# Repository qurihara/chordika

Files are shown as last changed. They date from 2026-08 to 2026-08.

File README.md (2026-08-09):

# Chordika &amp; Recorika

**Card-sized 3D-printed whistles. Swap a card, change the key.**

日本語版は [README.ja.md](README.ja.md) をご覧ください。

Eight fipple pipes are 3D-printed into a credit-card-sized plate (85.6 × 54 × 4 mm).

- **Chordika** — blow any three adjacent pipes in one breath and a tuned triad sounds.
  Twelve cards cover every key, and the position-to-chord mapping is *identical* on all of
  them, so the same hand motion transposes when you swap the card.
- **Recorika** — the scale counterpart: one octave of a major scale, lowest pipe on the
  left, highest on the right. Available in G, A♭ and A.

The data is published, so anyone with a 3D printer can make the same thing. Each card is exactly credit-card sized, so it travels in a wallet or a card case.

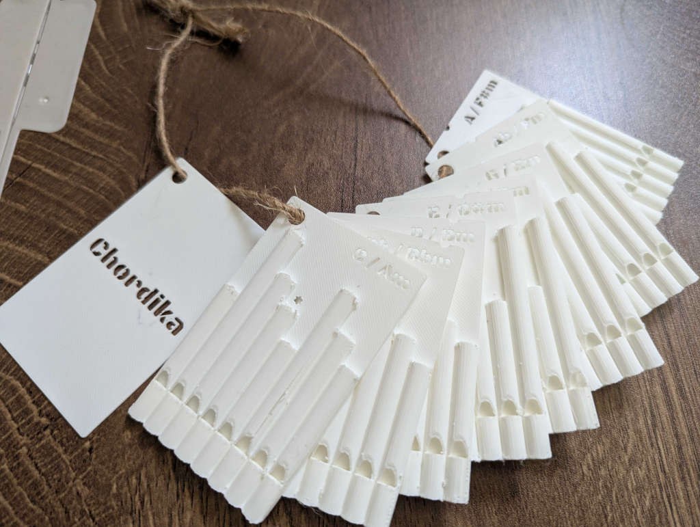
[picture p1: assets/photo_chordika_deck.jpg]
The twelve Chordika cards


**Project site: https://unryu.org/chordika/**

## The layout

On every Chordika card, the same pipes give the same chord function:

| Pipes | 1·2·3 | 2·3·4 | **3·4·5** | 4·5·6 | 5·6·7 | 6·7·8 |
|---|---|---|---|---|---|---|
| Chord | V | iii | **I** | vi | IV | ii |
| on C / Am | G | Em | **C** | Am | F | Dm |
| on G / Em | D | Bm | **G** | Em | C | Am |

Positions are counted from the left, with the windows facing up and the mouthpiece edge
towards you. The tonic pipe is marked with a ＊ on the card.

Each card therefore carries a major key *and* its relative minor. Only vii° (the
diminished triad) is missing.

This works because the notes follow the **degree chain 2·4·6·1·3·5·7·2** rather than pitch
order, which makes every three adjacent pipes a diatonic triad. On the card that chain runs
from the right-hand end towards the left.

## What's in this repository

```
index.html          project site (Japanese / English)
stl/                print data — 12 Chordika cards, 3 Recorika cards, 1 cover, 2 box parts
stl/inverted/       bonus: the 12 Chordika cards with the pipe order mirrored
3mf/                pre-sliced files for the Bambu Lab A1 mini (PLA), the same 18 items
3mf/inverted/       the same 12 inverted cards, pre-sliced
video/              short clips of the cards being played
assets/             cheat sheets (JA/EN), chord maps for all 12 keys, photos and figures
```

**Hear them:** start with the [demo video on YouTube](https://www.youtube.com/watch?v=5BZod5VixxM).
The [project site](https://unryu.org/chordika/) also has short clips — chords on
Chordika, the scale on Recorika, and a tune played on it.

If you own a **Bambu Lab A1 mini**, the files in `3mf/` are already sliced with the
settings below and can be sent straight to the printer. They assume Bambu PLA Basic;
each card is about 8.5 g and takes roughly 1 h 15 min. For any other printer or
filament, slice the STL yourself using the settings below.

## Printing

- **0.08 mm layers, 0.5 mm outer wall.** The pipe walls are thin; do not print coarse.
- **No supports.** Print flat, as-is.
- **One card per plate.** Two cards on one plate double the time per layer, the edges cool
  and shrink, and the card warps. A brim alone will not stop it.
- **Brim about 5 mm, brim-to-object gap 0.** With a gap the brim never fuses to the part
  and holds nothing.
- White PLA works well. Translucent PETG is beautiful — the bores show through the plate.

**Remove any sharp spots before you blow into it.** A fresh print leaves fine burrs and
sharp corners, and this is an instrument you put to your lips — as printed it is not safe.
I have come close to cutting my mouth on one more than once. Run a finger along the card's
edges and around the mouthpieces, and smooth anything that catches with a file or the back
of a knife.

All eight mouthpieces sit in a straight line along one edge of the card: put your lips on
that edge and slide along it. Blow with about as much breath as a recorder — too hard and
the pipe jumps an octave.

## Cover card and box

The **cover** (`chordika_cover.stl`) is a 0.5 mm plate with no pipes and "Chordika" cut
through it. It shares the cards' outline and strap-hole position, so it stacks on top of
the twelve and threads onto the same cord.

The **box** is two parts: an open tray (`chordika_box_base.stl`) and a lid that slips over
its outside (`chordika_box_lid.stl`). All thirteen cards lie flat inside, and the lid
carries the same cut-through lettering as the cover. A scallop on each long side lets you
pinch a card out. Closed, it is about 94 × 62 × 57 mm.

The box holds no pipes, so it prints at **ordinary 0.2 mm layers with no supports** — no
need for the fine settings the cards require.

## How it was designed

Pipe length and pitch were fitted from real printed-and-blown pipes as `f = A/(L+e)`.
Solving it backwards turns a wanted note into a length, so a generator written in Python
(trimesh + manifold3d) emits the whole card from a key name. The plate thickness is fixed
at 0.5 mm — exactly the floor thickness of the pipes; any thicker and it eats into the
bore and the card goes silent.

## Licence

[CC BY-NC-ND 4.0](https://creativecommons.org/licenses/by-nc-nd/4.0/) — see [LICENSE](LICENSE).

**You may** print these for your own use, play them, and share them unchanged with credit,
including non-commercially in classes and workshops.
**You may not** use them commercially (selling prints, paid services) or distribute
modified data. If you want different terms, please get in touch.

---

From the "AI whistle-making" project by Kazutaka Kurihara (Tsuda University).

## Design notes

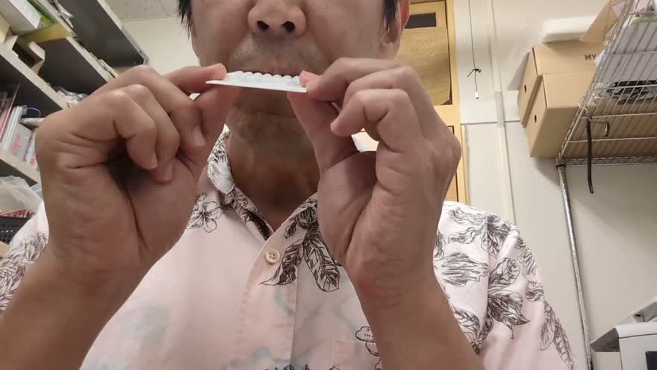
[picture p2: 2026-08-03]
assets/poster_chordika.jpg

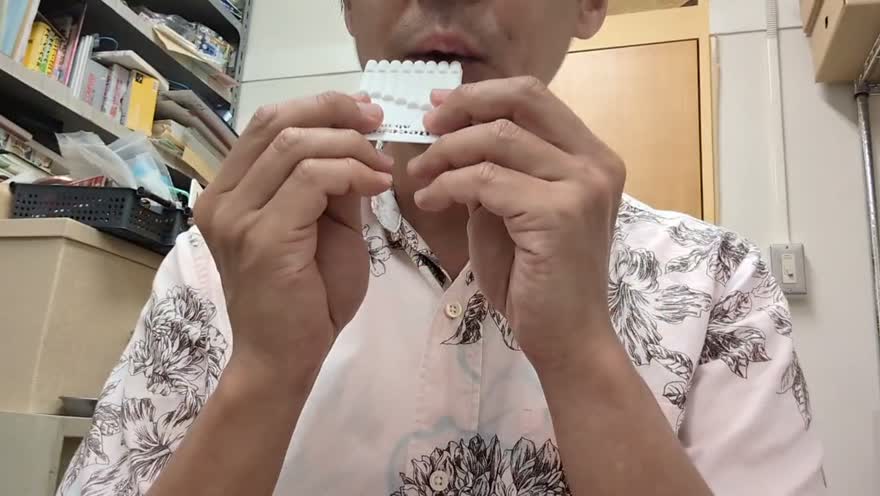
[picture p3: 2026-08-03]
assets/poster_recorika_kirakira.jpg

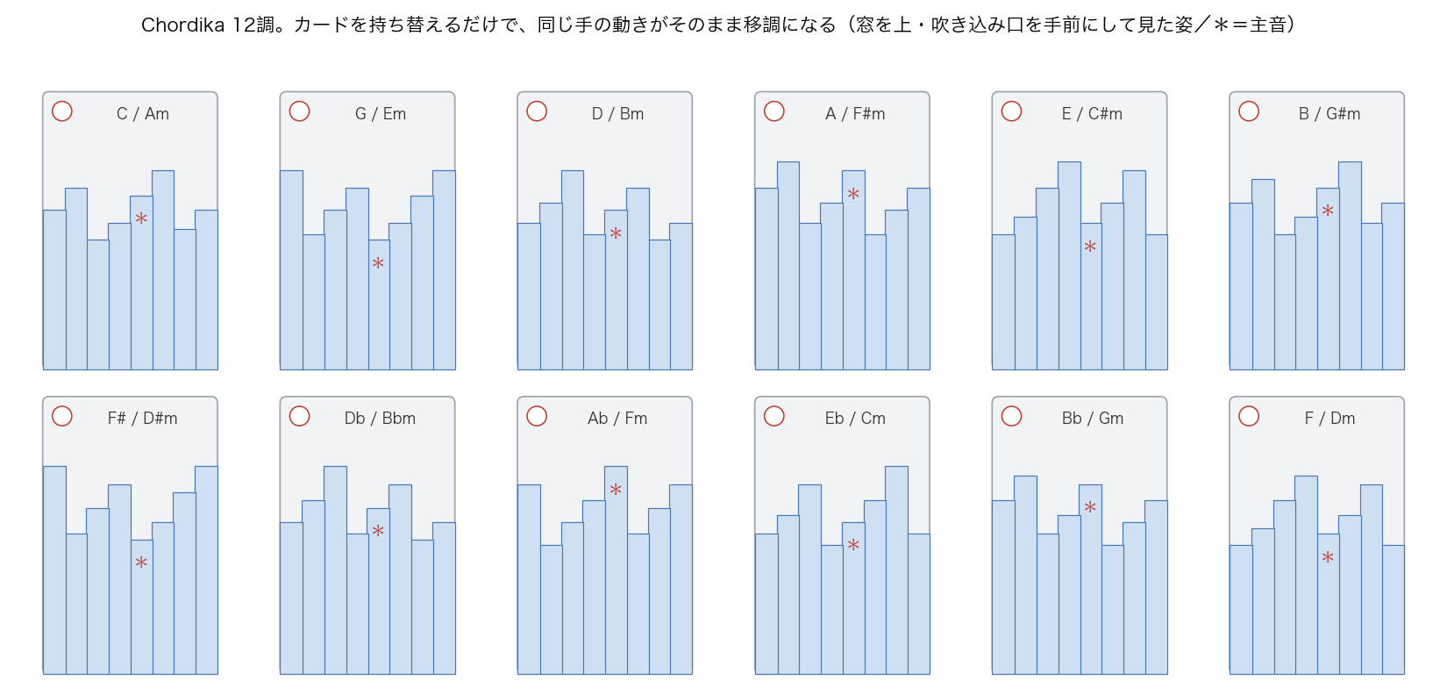
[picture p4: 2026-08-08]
assets/overview_12keys.png

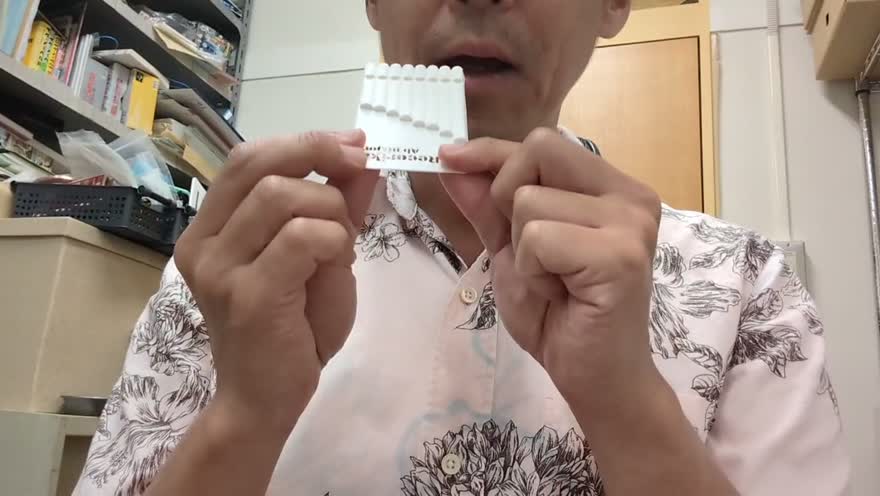
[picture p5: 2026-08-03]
assets/poster_recorika_octave.jpg

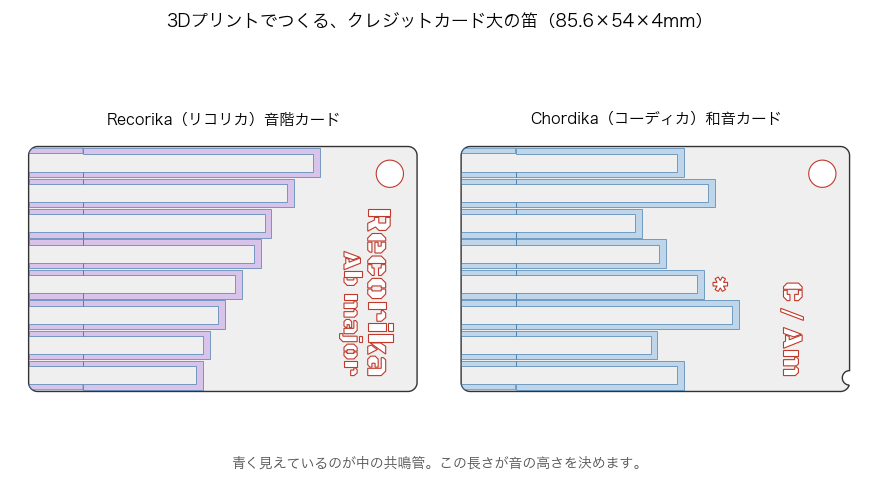
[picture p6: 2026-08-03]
assets/overview_pair.png

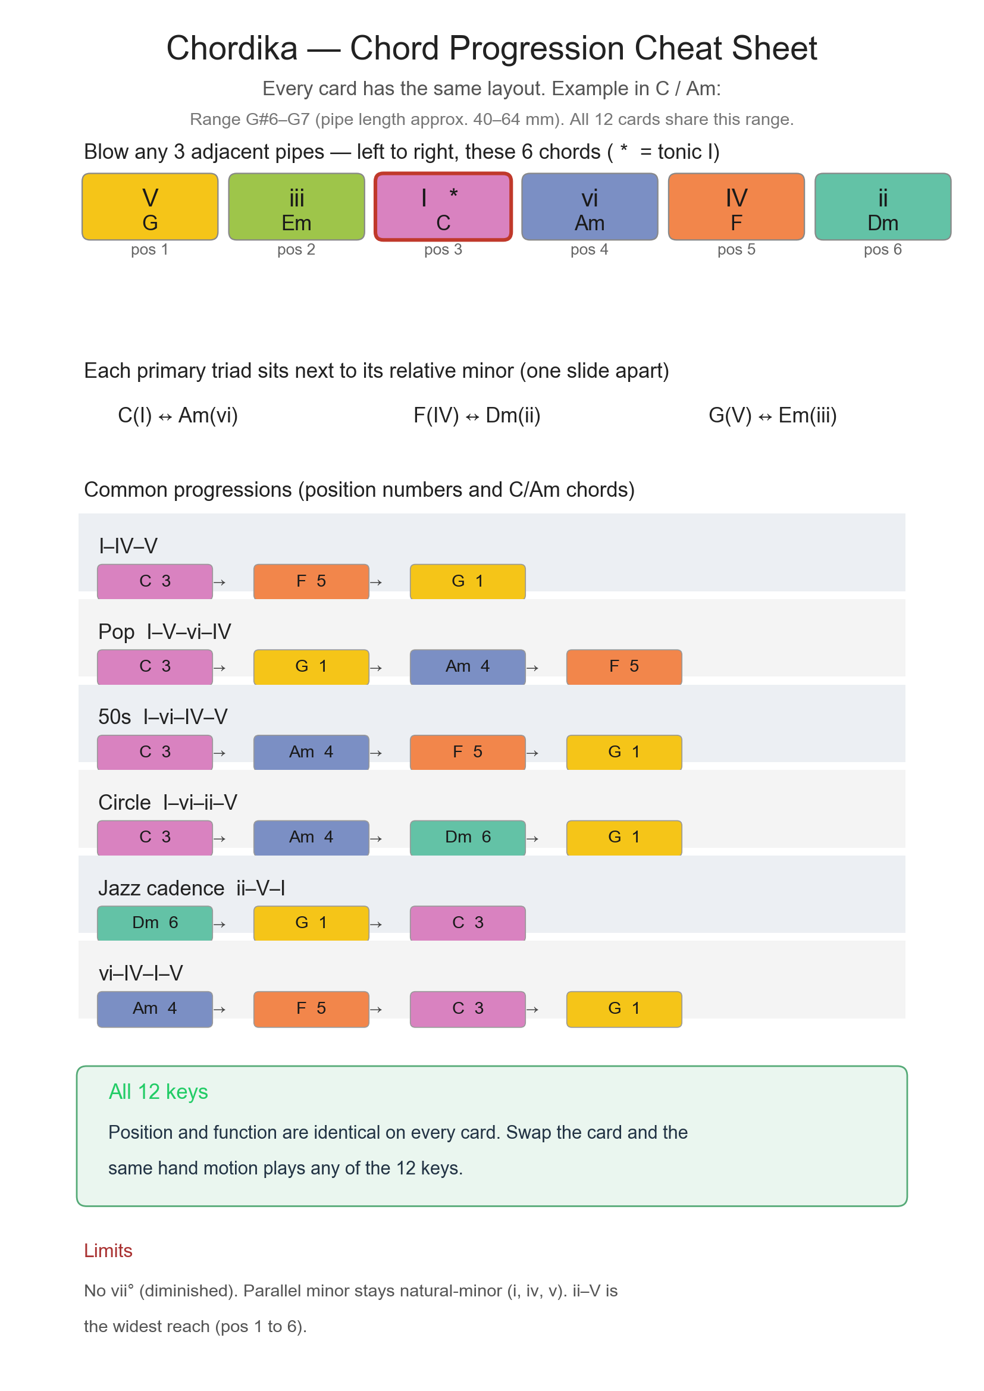
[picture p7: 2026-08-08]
assets/cheatsheet_en.png

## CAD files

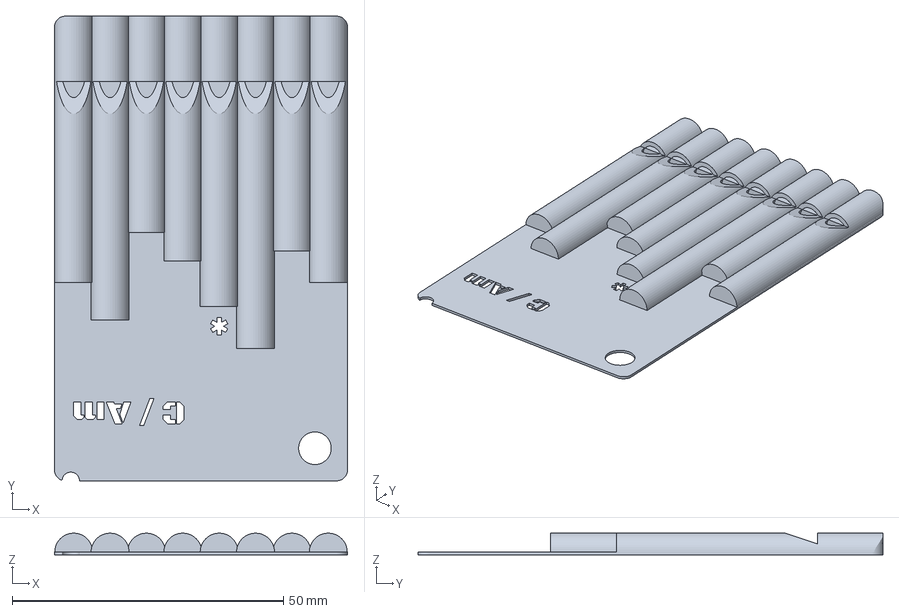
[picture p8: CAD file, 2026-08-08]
3mf/inverted/chordika_C_Am_a1mini_pla.gcode.3mf
54.0 x 85.6 x 4.00 mm

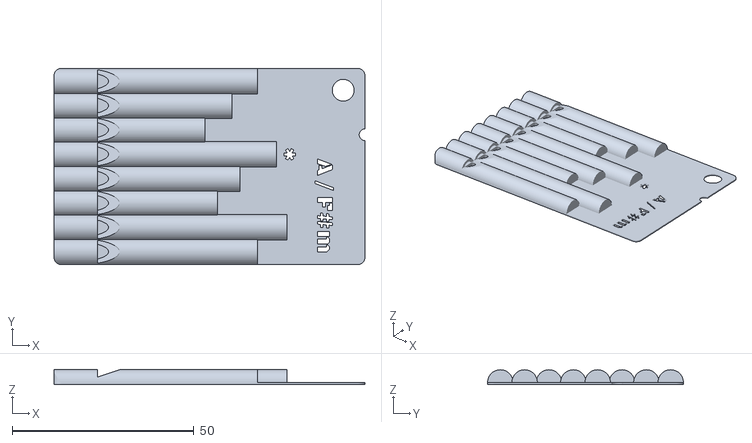
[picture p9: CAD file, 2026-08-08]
stl/inverted/chordika_A_Fsm.stl
85.6 x 54.0 x 4.00

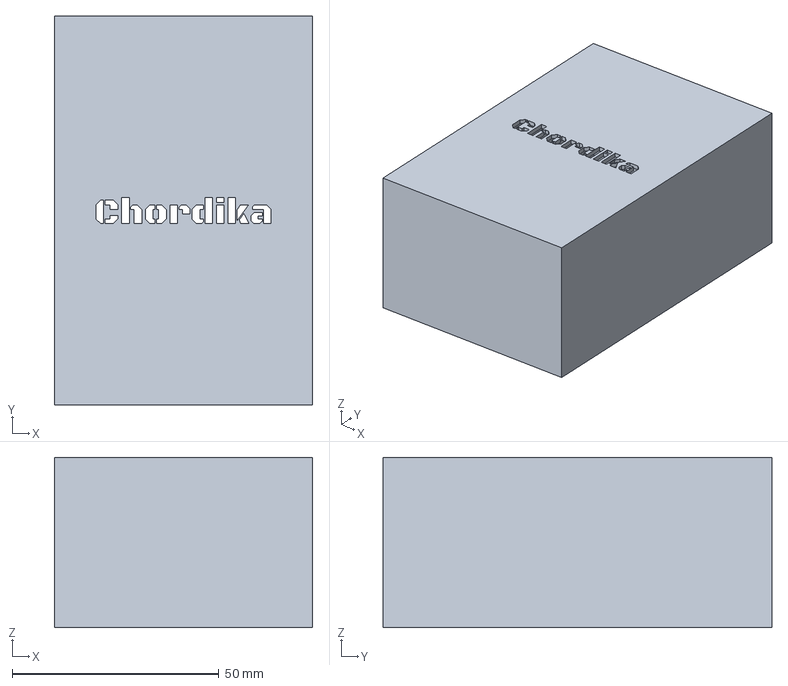
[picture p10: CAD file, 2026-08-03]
3mf/chordika_box_lid_a1mini_pla.gcode.3mf
62.4 x 94.0 x 41.2 mm

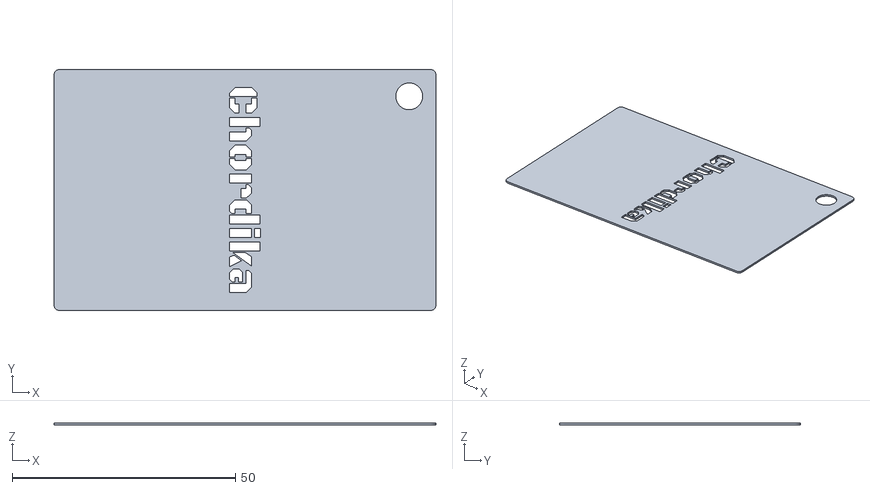
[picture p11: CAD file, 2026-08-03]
stl/chordika_cover.stl
85.6 x 54.0 x 0.5

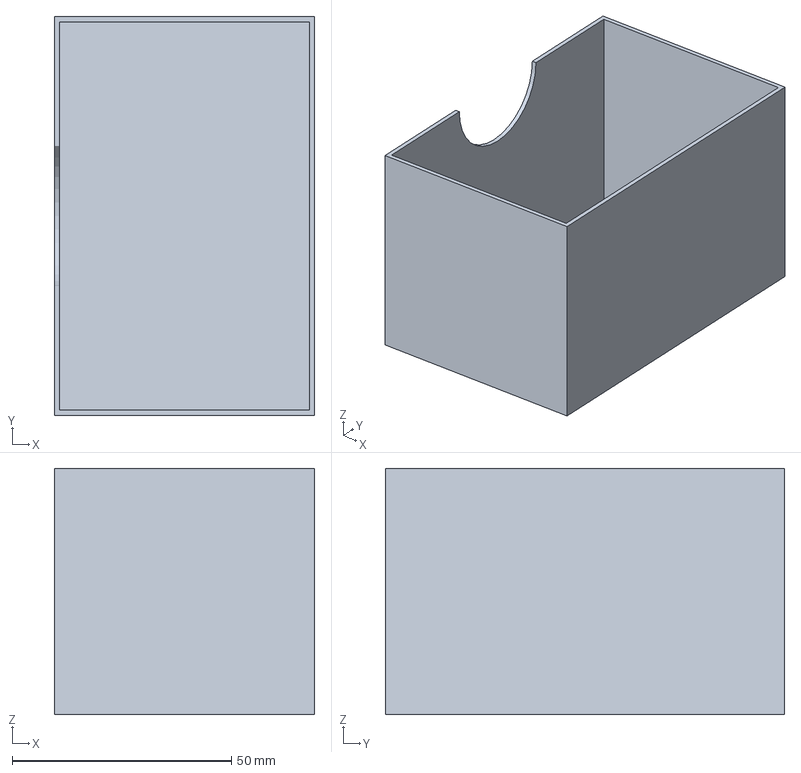
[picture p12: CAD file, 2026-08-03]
3mf/chordika_box_base_a1mini_pla.gcode.3mf
59.4 x 91.0 x 56.2 mm

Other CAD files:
3mf/recorika_G_a1mini_pla.gcode.3mf
stl/inverted/chordika_F_Dm.stl
stl/recorika_A.stl
3mf/inverted/chordika_D_Bm_a1mini_pla.gcode.3mf
3mf/recorika_A_a1mini_pla.gcode.3mf
stl/recorika_G.stl
3mf/inverted/chordika_A_Fsm_a1mini_pla.gcode.3mf
stl/inverted/chordika_Bb_Gm.stl
3mf/chordika_cover_a1mini_pla.gcode.3mf
3mf/inverted/chordika_Eb_Cm_a1mini_pla.gcode.3mf
stl/chordika_box_lid.stl
stl/inverted/chordika_Fs_Dsm.stl
3mf/inverted/chordika_G_Em_a1mini_pla.gcode.3mf
3mf/chordika_A_Fsm_a1mini_pla.gcode.3mf
3mf/chordika_Ab_Fm_a1mini_pla.gcode.3mf
3mf/chordika_B_Gsm_a1mini_pla.gcode.3mf
3mf/chordika_Bb_Gm_a1mini_pla.gcode.3mf
3mf/chordika_C_Am_a1mini_pla.gcode.3mf
3mf/chordika_D_Bm_a1mini_pla.gcode.3mf
3mf/chordika_Db_Bbm_a1mini_pla.gcode.3mf
3mf/chordika_E_Csm_a1mini_pla.gcode.3mf
3mf/chordika_Eb_Cm_a1mini_pla.gcode.3mf
3mf/chordika_F_Dm_a1mini_pla.gcode.3mf
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

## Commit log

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2026-08-03 STLを公開し、RecorikaとChordikaの2本立てにサイトを作り直した
    このリポジトリを Chordika/Recorika の公開の主体にする。ai-fue リポジトリは暗号笛など
    別プロジェクトも同居していて複雑なので、印刷して遊べるものだけをここに集める。
    印刷データを公開した。Chordika 12調と Recorika 1枚の STL を stl/ に置いた。README に
    「印刷データはまだ置いていない」と書いてあったが、これは事実でなくなったので直した。
    サイトを作り直した。7月20日版は Chordika だけを扱っていたので、Recorika を対等に並べる
    構成にした。位置と和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
    [chordika_A_Fsm.stl, chordika_Ab_Fm.stl, chordika_B_Gsm.stl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]
2026-08-03 A1 mini・PLA用のスライス済み3mfを13枚ぶん追加した
    STLだけだと、笛が鳴るかどうかを左右する設定（0.08mm層・0.5mm外壁・ブリム・サポートなし）
    を各自が入れ直す必要がある。A1 miniを持っている人がそのまま印刷に送れるよう、スライス済み
    の3mfを 3mf/ に置いた。Chordika 12調とRecorika 1枚で計13ファイル。
    フィラメントは特定の色ではなく汎用の Bambu PLA Basic を前提にした。冷却だけは実機で成立
    した設定（床5層はファン停止、常用40%）を移してある。1枚あたり約8.5g・1時間15分。
    作るときにCLIの罠を2つ踏んだので記録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
    [chordika_A_Fsm_a1mini_pla.gcode.3mf, chordika_Ab_Fm_a1mini_pla.gcode.3mf, chordika_B_Gsm_a1mini_pla.gcode.3mf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]
2026-08-03 実写を載せ、STLと3mfをGitHubで公開している旨を明記した
    これまで図版だけだったサイトとREADMEに、実際に刷ったカードの写真を入れた。表紙は
    白いPLAで刷った12枚を紐で束ねて扇状に広げたもので、大きさと質感、そしてストラップ穴で
    束ねられることが一目で伝わる。Recorikaの節にも実物の写真を置き、左の長い管が最低音で
    右へ行くほど短く高くなることを、図ではなく現物で示した。
    図版のうち俯瞰図は、しくみの節へ移して活かした。中の共鳴管が見える図なので、写真では
    分からない「管の長さが音の高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
2026-08-03 実際に吹いている動画3本を載せた
    音の出るものなので、写真だけでは伝わらない。実演の短い動画を video/ に置き、サイトに
    埋め込んだ。Chordikaは口を横にすべらせて和音が次々に変わるところ（15秒）、Recorikaは
    ドレミが上がっていくところ（5秒）と、その音階で曲を吹いたところ（8秒）である。
    再エンコードはせず、余分なデータストリームを外して moov を先頭へ移した（faststart）。
    読み込みながら再生できるようになる。合計12.7MB。
    ページ側は preload="none" とポスター画像にした。動画3本を無条件に読ませる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
2026-08-03 売りを「電池がいらない」から「3Dプリントできて持ち歩ける」に直した
    「電池もセンサーもありません」と書いていたが、これは差別化になっていない。普通の笛だって
    電池は要らない。栗原さんの指摘のとおりで、この作品が他と違うのは次の2点である。
    ひとつは3Dプリントできること。データを公開しているので、プリンタさえあれば誰でも同じ
    ものを刷れる。もうひとつはクレジットカードとまったく同じ大きさであること。財布や
    カードケースに入れて持ち歩ける。楽器としては珍しい性質で、12枚束ねて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
2026-08-03 図から「電源のいらない」を外し、「どうやって作ったか」の節を削除した
    俯瞰図の見出しに「電源のいらない楽器」と書いていたが、普通の笛も電源は要らないので
    差別化になっていない。「3Dプリントでつくる、クレジットカード大の笛（85.6×54×4mm）」に
    差し替え、共鳴管の説明を図の下に添えた。この図はProtopediaにも上げてあるので、
    そちらも同じファイルで差し替えられる。
    「どうやって作ったか」の節を丸ごと削除した。較正式やPythonの生成器の話は、このサイトを
    訪れる人（印刷して使いたい人）に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
2026-08-03 デッキの表紙と収納箱を公開に加えた
    カードだけを公開していたが、実際に使うときは表紙を重ねて紐で束ね、箱に収めている。
    手元にあるものが公開データに無いのは不親切なので、表紙(0.5mm・Chordikaの文字を切り抜き)と
    箱の2部品(上の開いた本体・外側にかぶせる蓋)を stl/ と 3mf/ に加えた。
    表紙の生成器が残っていなかったので harmonica_deck/make_cover_card.py として起こし直した
    (実体は fue/namecard.py の build_cover)。生成したものは実機で刷った表紙と体積が完全に
    一致することを確認済みである。箱は harmonica_deck/make_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
    [chordika_box_base.stl, chordika_box_base_a1mini_pla.gcode.3mf, chordika_box_lid.stl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]
2026-08-03 デモ映像をヒーローに埋め込んだ
    日本語版と英語版の2本があるので、言語切り替えに合わせて出し分ける。写真のすぐ下に置き、
    ページを開いてすぐ音を確かめられるようにした。
    埋め込み先は youtube-nocookie.com にしてある。通常の youtube.com は再生前から閲覧者に
    クッキーを置くので、こちらを使う。読み込みは loading="lazy" にして、ページの表示を
    待たせないようにした。
    比率は 16:9 を aspect-ratio で保つ。画面幅に追従し、横スクロールは出ない。
    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
2026-08-04 刷った直後のバリで口を切らないための注意を入れた
    刷り上がりには細かいバリや角が残る。口を当てて吹く道具なので、そのままでは危ないという
    実際の経験（何度か口を切りそうになった）を注意書きにした。
    吹きかたの説明の手前に置いてある。順番が逆だと、読んだ人がそのまま口に当ててしまう。
    既存の warn（橙）とは別に danger（赤・枠を太く）を足した。印刷設定の助言と、怪我を
    避けるための注意は重みが違うので、見た目で区別する必要がある。明暗どちらの配色でも
    見出しの色が沈まないよう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
2026-08-04 日本語版のデモ映像を差し替えた
    日本語版の動画を hUCn4gRVEYY に入れ替えた。英語版 D532YUIkJ7o はそのままである。
    サイトの埋め込みとREADMEの案内の2箇所を直し、旧IDが残っていないことを確認した。
    差し替え先が公開されていて埋め込めることは、oEmbedで題名を取得して確かめてある。
2026-08-04 英語版のデモ映像も差し替えた
    英語版の動画を mi-en3c57SM に入れ替えた。これで日英とも新しい版になった。
    公開されていて埋め込めることは、oEmbedで題名を取得して確かめてある。
    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
2026-08-08 図の左右を実物に合わせ、逆並び版を公開した
    対応表12枚・早見表・一覧図は、実物を鏡に映した並びだった。実機のSTLを走査して測ったところ、
    カードを窓が上・吹き込み口が手前に置くと主音の＊は左から5本目なのに、図は4本目に描いていた。
    図に従って左から数えると、位置1-2-3で Dm のつもりが G が鳴る。すべて見たままの並びに直し、
    位置番号も左から1..8に振り直した。
    サイトとREADMEの表も新しい番号に合わせた。C/Am なら位置3-4-5がトニックC、位置1-2-3がGに
    なる。移調の例も「3・4・5 → 5・6・7 → 1・2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
    [chordika_A_Fsm.stl, chordika_A_Fsm_a1mini_pla.gcode.3mf, chordika_Ab_Fm.stl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]
2026-08-08 デモ映像を作り直した版に差し替えた
    図の左右を直したので動画も作り直し、日英とも新しい版に入れ替えた。
    日本語 -cbyvgwa6VM、英語 5BZod5VixxM。サイトの埋め込みとREADMEの案内を直し、
    旧IDが残っていないことを確認した。両方とも公開されていて埋め込めることは
    oEmbedで題名を取得して確かめてある。
2026-08-09 Recorikaを3調に増やした（G・A♭・A）
    A♭の上下に1半音ずらした G major と A major を実機で刷り、全8音が鳴ることを確認した。
    これでRecorikaは打ち止めである。1オクターブは根音から13半音ぶんの幅を要り、この笛が
    安定して鳴る音域は14半音しかないので、根音を置ける音は物理的に3つしかない。
    G major G6–G7 67.2〜39.9mm
    A♭ major A♭6–A♭7 64.2〜38.4mm
    A major A6–A7 61.3〜36.9mm
    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
    [recorika_A.stl, recorika_A_a1mini_pla.gcode.3mf, recorika_G.stl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]
2026-10-25 Recorika Chromatic と Recorika Chromatic Square を公開した：紹介の節（演奏映像「おじいさんの11ヶ月」、試作の写真、特徴、2つの形）、STL 2点、H2D・白い PETG のスライス済み 3mf 3点、README の追記
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2026-11-02 Recorika Chromatic Tiny を「最小サイズ」として公開した：STL、H2D・白い PETG のスライス済み 3mf、写真2枚（ノギスと並べた写真と斜めから）、サイトの紹介・3つの形・ダウンロード・いまの状態の追記、README（日英）の追記
    中身は ai-fue の irecorika_flutes v1.3（タグ Recorika_Chromatic_tiny_v1.3）。66.0 × 53.8 × 4 mm で、外形はクレジットカードの内側に収まる。2026-11-02 に H2D・白い PETG・詰まった層 70 mm/s で印刷し、12本すべて鳴った。
2026-11-02 Recorika Chromatic の「形」「shape」を「モデル」「model」に改め、Tiny の説明から作りの説明と最低音を響かせるコツを除いた（ProtoPedia の栗原さんの修正に合わせた。日英、サイトと README）
2026-11-03 Recorika Chromatic Tiny の標準版を v1.3.4（キーホルダー穴つき）に替えた：STL とスライス済み 3mf（H2D・右ノズル・白い PETG、実際に印刷して12本とも鳴ったファイル）を差し替え、ノギスと並べた写真を v1.3.4 を印刷したものに差し替えた。文言は変えていない
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
